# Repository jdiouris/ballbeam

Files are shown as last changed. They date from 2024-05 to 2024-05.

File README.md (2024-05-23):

# Asservissement d'une balle sur un plan incliné
Ce dépôt fournit les fichiers permettant de réaliser l'asservissement d'une balle sur un plan incliné en utilisant un corecteur PID. 
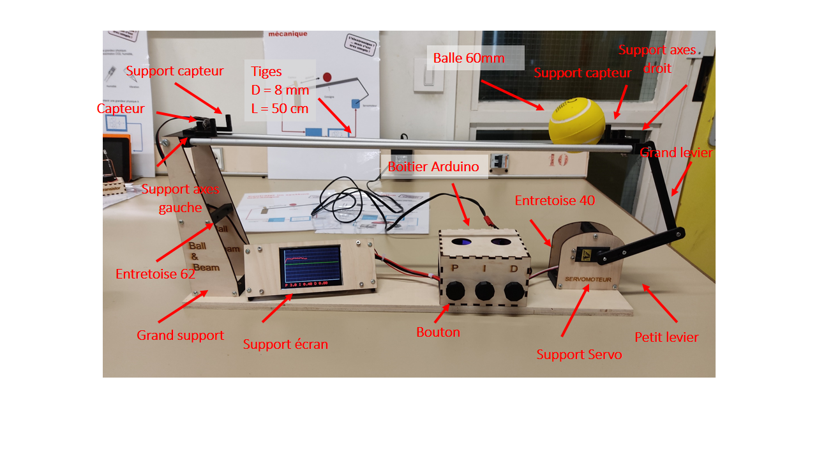
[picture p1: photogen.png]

## Principe
La balle roule sur deux axes en aluminium dont l'inclinaison est réglée par un système de leviers relié à un servomoteur standard. La position de la balle est déterminée par un capteur de distance VL53L0X, que l'on peut trouver monté sur une carte par exemple [ici](https://www.amazon.fr/gp/product/B086TSKJBT/ref=ppx_yo_dt_b_search_asin_title?ie=UTF8&psc=1). 

L'asservissement est réalisé par un Arduino Uno. L'affichage graphique est réalisé au moyen d'un arduino Mega et d'un afficheur graphique. Les deux cartes Arduino communiquent par un lien série.

## Câblage
Les différents circuits sont interconnectés selon le tableau suivant.

| PIN Arduino | Description |
| --- | ---  |
| D5 | Impulsion servo|
| A0 | Potentiomètre 0 |
| A1 | Potentiomètre 1 |
| A2 | Potentiomètre 2 |
| D3 | Alim VL53L0X |
|SCL | SCL VL53L0X |
|SDA | SDA VL53L0X |
| D1 TX| lien série, connecté au D53 de l'arduino Mega |

La figure ci-desous donne le détail du cablage.

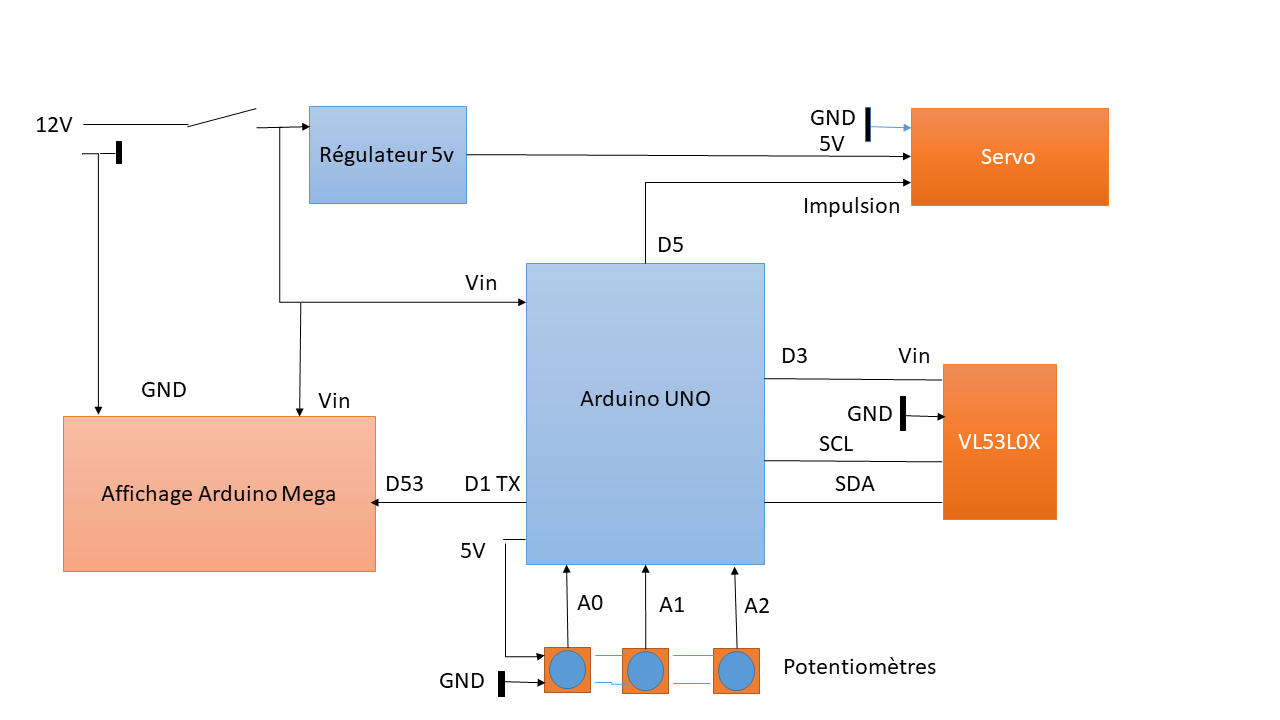
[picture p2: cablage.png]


## Mécanique

La mécanique est réalisée en découpe et gravure laser dans du contreplaqué 3mm et en impression 3D.

Les pièces dont décrites ici:

|Pièces | Fichiers source (conception) | Fichiers de fabrication | Nombre d'exemplaires |
| --- | ---  | --- |  --- |
|Boitier arduino | boitier.lbrn2| boitier.dxf | 1 |
| Support servo | supservo.lbrn2 | supservo.dxf | 1 |
| Support écran | supecran.lbrn2 | supecran.dxf | 1|
| Support  gauche | grandsupport.lbrn2 | grandsupport.dxf | 1|
| Support axes droit | supaxedroit.scad | supaxedroit.stl | 1|
| Support axe gauche | supaxegauche.scad | supaxegauche.stl | 1 |
|petit levier | levier.scad | petitlevier.stl | 1|
|grand levier | levier.scad | grandlevier.stl | 1 |
|Support carte Mega | megasupport.scad | megasupport.stl | 1 |
|Support plaque écran | msupplaqueecrant.scad | supplaqueecran.stl | 2 \
|Support capteur | supcapt.scad | supcapt.stl | 2 
| entretoise 62 |entretoises.scad | entretoise62.stl |4|
| entretoise 40 |entretoises.scad | entretoise40.stl |3|

Les fichiers dxf sont destiné à une découpe laser (contreplaqué 3mm). Les fichiers dxf à une impression 3D.

Les pièces sont indiquées sur la photo en haut de page. La photo ci-dessous donne un détail sur l'écran.

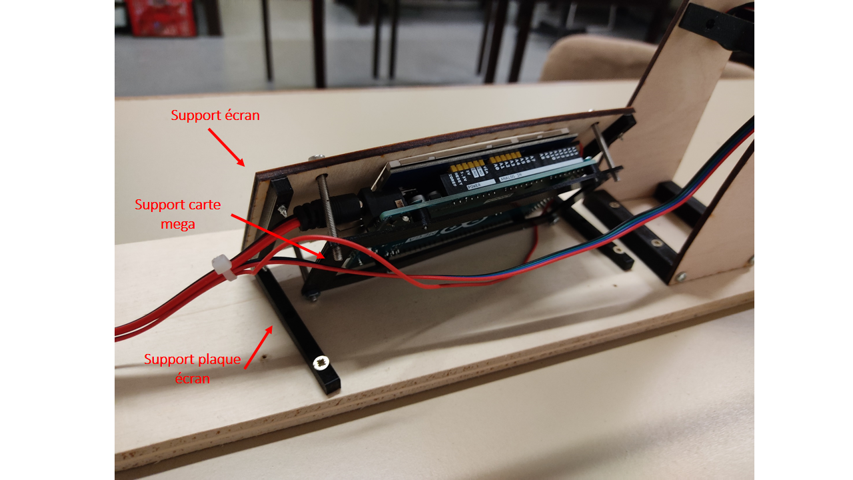
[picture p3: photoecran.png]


## Les programmes

Les deux programmes arduino sont dans les répertoires asservissement et tftgraph.

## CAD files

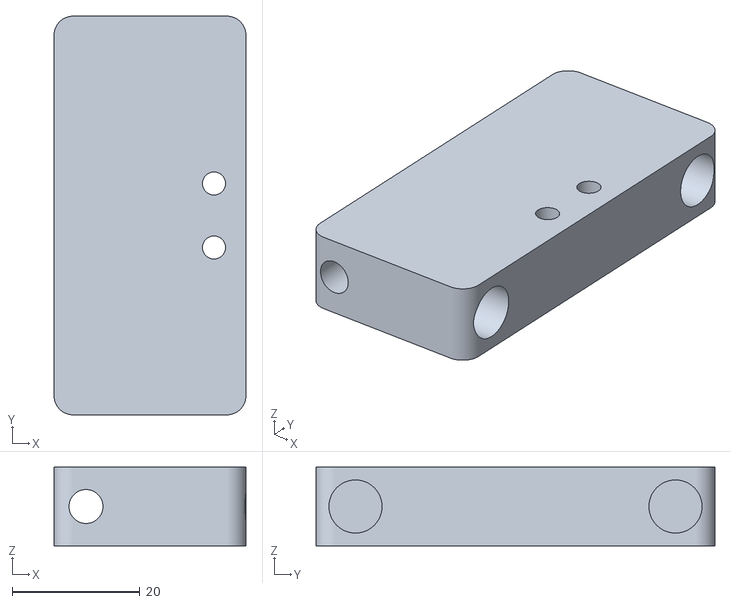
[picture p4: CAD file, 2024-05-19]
Mecanique/supaxedroit.stl
30.0 x 62.3 x 12.3

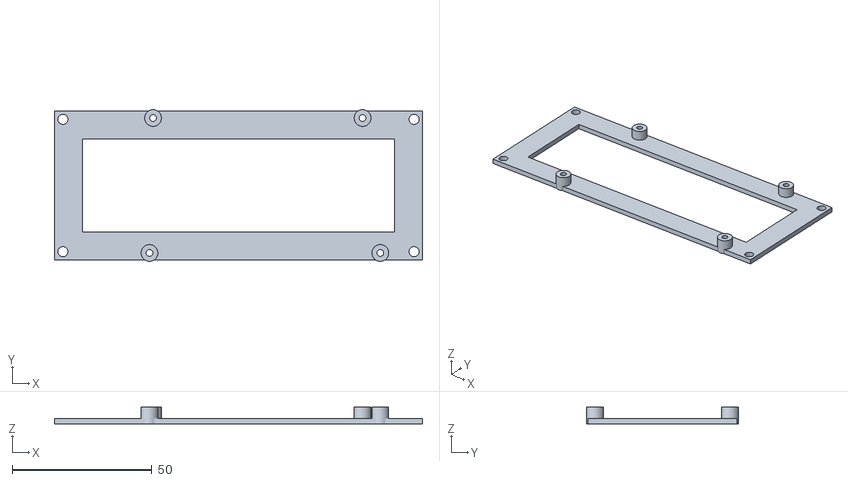
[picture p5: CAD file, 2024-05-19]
Mecanique/megasupport.stl
131.6 x 54.3 x 6.00

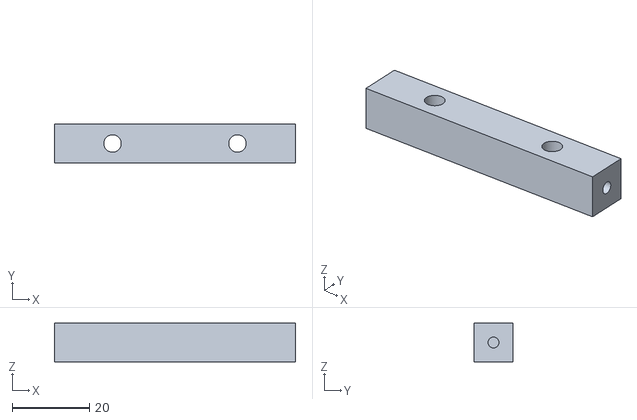
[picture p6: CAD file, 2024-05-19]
Mecanique/entretoise62.stl
62.3 x 10.0 x 10.0

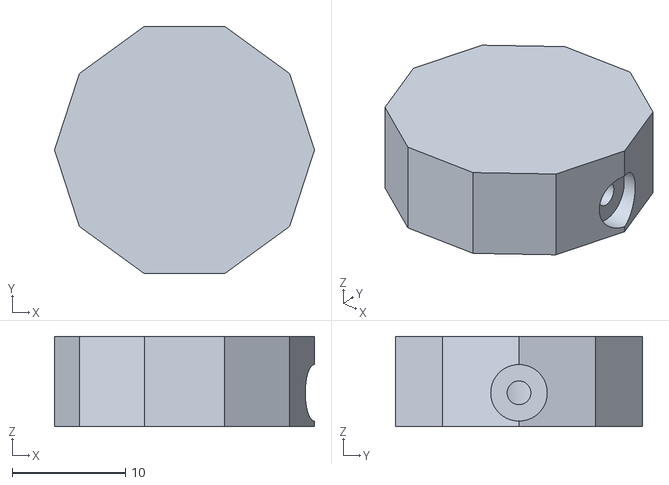
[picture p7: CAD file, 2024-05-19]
Mecanique/bouton.stl
23.0 x 21.9 x 8.00

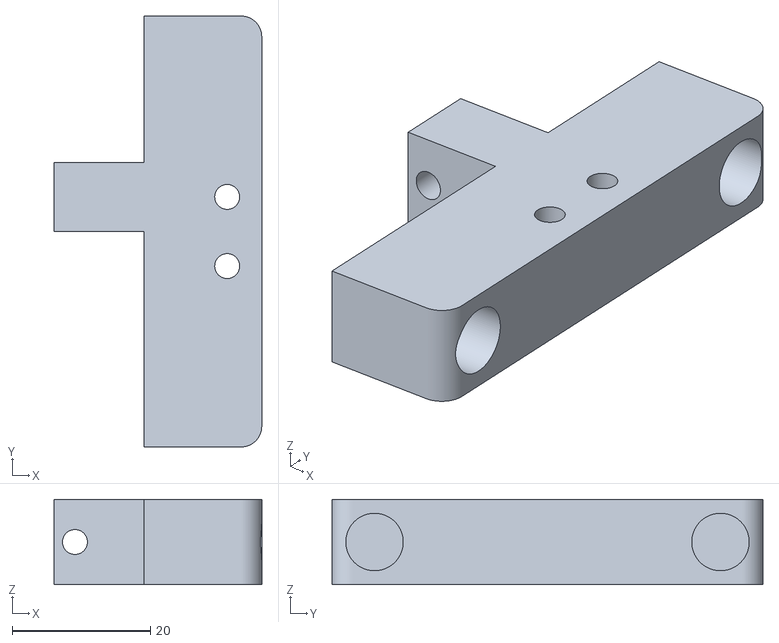
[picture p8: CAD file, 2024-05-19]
Mecanique/supaxegauche.stl
30.0 x 62.3 x 12.3

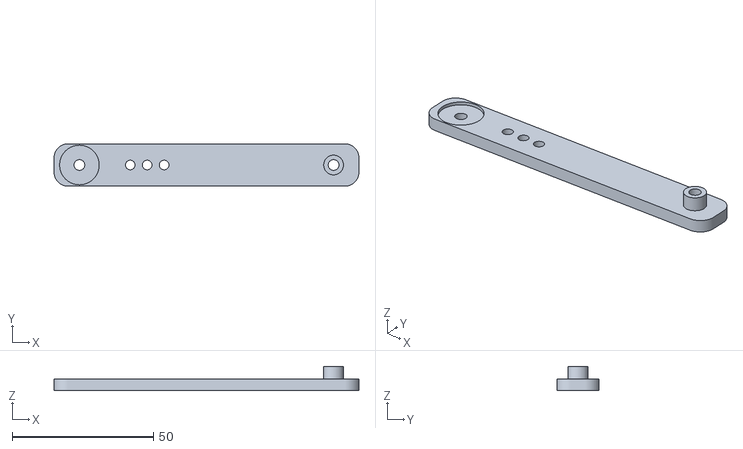
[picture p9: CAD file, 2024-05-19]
Mecanique/petitlevier.stl
108.0 x 15.0 x 8.50

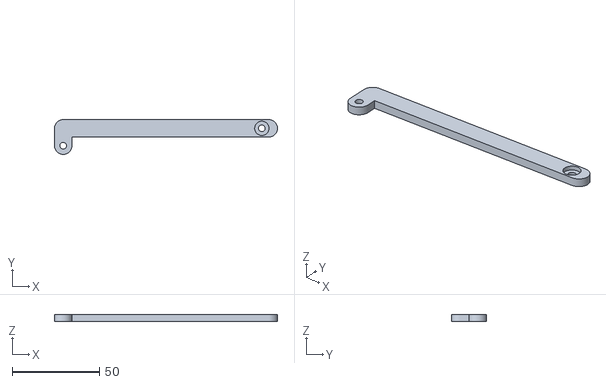
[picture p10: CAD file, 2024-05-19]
Mecanique/grandlevier.stl
128.0 x 20.0 x 4.00

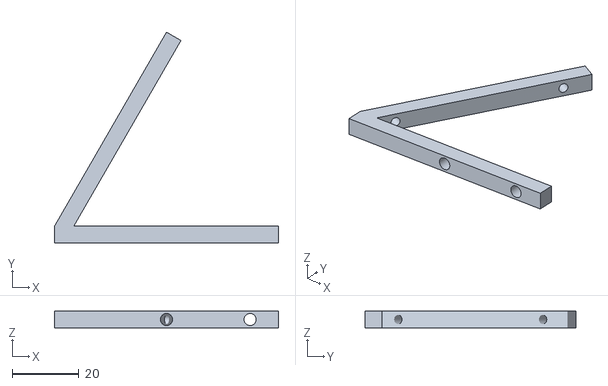
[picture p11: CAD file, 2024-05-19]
Mecanique/supplaqueecran.stl
67.0 x 63.0 x 5.00

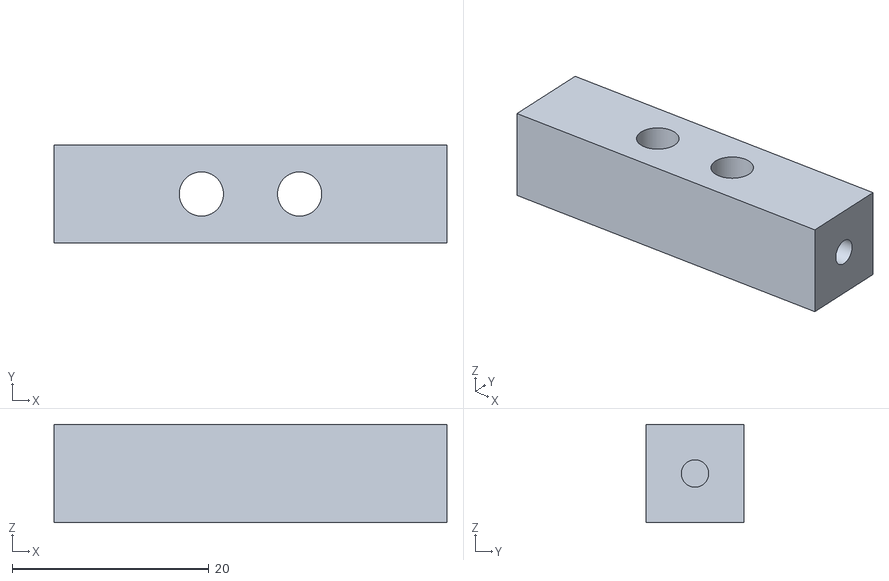
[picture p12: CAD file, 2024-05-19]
Mecanique/entretoise40.stl
40.0 x 10.0 x 10.0

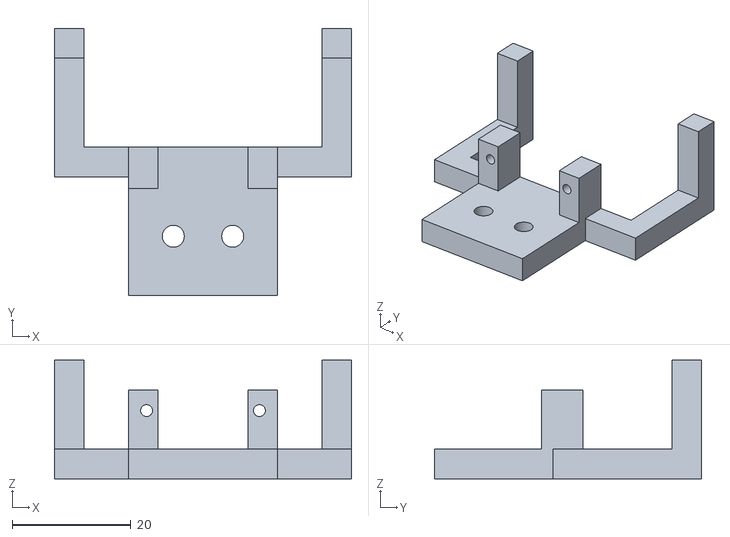
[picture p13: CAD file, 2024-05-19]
Mecanique/supcapt.stl
50.0 x 45.0 x 20.0

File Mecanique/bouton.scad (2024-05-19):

D=23;
Da=6+0.5;
H=8;
$fn=100;

difference()
{
    cylinder(d=D,h=H,$fn=10);
    cylinder(d=Da,h=H-2);
    translate([0,0,(H-2)/2]) rotate([0,90,0]) cylinder(d=2.1,h=D/2);
    translate([D/2-2,0,(H-2)/2]) rotate([0,90,0]) cylinder(d=5,h=D/2);
}

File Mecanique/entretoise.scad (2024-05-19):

//W=62.3;
W=40;
H=10;
$fn=100;

difference()
{
    cube([W,H,H]);
    translate([-1,5,5]) rotate([0,90,0]) cylinder(h=13,d=2.8);
    translate([W-12,5,5]) rotate([0,90,0]) cylinder(h=13,d=2.8);
    translate([15,5,-1]) cylinder(h=15,d=4.5);
    translate([W-15,5,-1]) cylinder(h=15,d=4.5);
}

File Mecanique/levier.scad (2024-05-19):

W=15;
W2=10;
D=14;
E=4;
L2=90+D+4;
L1=110+D+4;
$fn=100;

module rcube(x,y,z,d)
{
    union()
    {
        translate([d/2,d/2,0]) cube([x-d,y-d,z]);
        translate([d/2,0,0]) cube([x-d,d,z]);
        translate([d/2,y-d,0]) cube([x-d,d,z]);
        translate([0,d/2,0]) cube([d,y-d,z]);
         translate([x-d,d/2,0]) cube([d,y-d,z]);
        translate([d/2,d/2,0]) cylinder(h=z,d=d);
        translate([x-d/2,d/2,0]) cylinder(h=z,d=d);
         translate([d/2,y-d/2,0]) cylinder(h=z,d=d);
        translate([x-d/2,y-d/2,0]) cylinder(h=z,d=d);
    }
    
}

module petitLevier()
{
    difference()
    {
        union()
        {
        rcube(L2,W,E,10);
            translate([D/2+2+90,W/2,E]) cylinder(h=E+0.5, d=7);
        }
        translate([D/2+2,W/2,E-1]) cylinder(h=2, d=D);
        translate([D/2+2,W/2,-1]) cylinder(h=20, d=3.8);
        translate([D/2+2+18,W/2,-1]) cylinder(h=20, d=3.4);
        translate([D/2+2+24,W/2,-1]) cylinder(h=20, d=3.4);
        translate([D/2+2+30,W/2,-1]) cylinder(h=20, d=3.4);
        
        translate([D/2+2+90,W/2,-1]) cylinder(h=20, d=3.8);
        
    } 
}

module grandLevier()
{
    difference()
    {
        union()
        {
        rcube(L1,W2,E,10);
            //translate([D/2+2+110,W/2,E]) cylinder(h=E+0.5, d=12);
            rcube(10,2*W2,E,10);
        }
        //translate([D/2+2,W/2+W,E-1]) cylinder(h=2, d=D);
        translate([5,W2/2+W2,-1]) cylinder(h=20, d=3.8);
        
        
        translate([D/2+2+110,W2/2,2]) cylinder(h=20, d=8.2);
        translate([D/2+2+110,W2/2,-1]) cylinder(h=20, d=3.8);
        
    } 
}
    
//petitLevier();
mirror([0,1,0]) grandLevier();

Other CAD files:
Mecanique/boitier.dxf
Mecanique/supservo.dxf
Mecanique/grandsupport.dxf
Mecanique/supecran.dxf
Mecanique/megasupport.scad
Mecanique/supaxedroit.scad
Mecanique/supaxegauche.scad
Mecanique/supcapt.scad
Mecanique/supplaqueecran.scad

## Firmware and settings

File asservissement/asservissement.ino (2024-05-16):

#include <Servo.h>
#include "Adafruit_VL53L0X.h"
#include <MsTimer2.h>

Adafruit_VL53L0X lox = Adafruit_VL53L0X();
/* ----------------------------------------*/
/* Démo sonar                              */
/*                                         */
// Broches                                  

// servo : 5
#define SERVOPIN 5

#define IND 2
#define ALIMC 3

// potentiometres
#define P1 1
#define P0 0
#define P2 2

// valeurs extrèmes servo
#define minServo 600
#define maxServo 1500
// PID
// float kp=1;
// float kd=0.5;
// float ki=0.4;
 float kp=3;
 float kd=0.8;
 float ki=0.4;
 
 float kkd=0;
 float kki=0;
 float Te=40e-3;
 float consigne=250;
 float erreur;
 float erreurP;
 float integrale;
 float deriv;
 // Moyennage mesures
 float alpha=0.8;
 float alphad=0.85;
 
 // Flag Timer période d'échantillonnage
 int fchange;
 float dCor;
 int distance;
 float angle;
 float angleZero;
// servo rotation
 Servo servo;
 //

int fcoef=1;   // envoie des coefs

int t=0;


void testAngle()
{
  float pas=1;
  angle=minServo;
  while (1)
  {
   if (angle>(maxServo-1)) pas=-1;
   if (angle<(minServo+1)) pas=1;
   servo.writeMicroseconds(angle);
   Serial.print(angle);Serial.println();
   delay(4); 
  }
}

// Interruprtion toute les période d'échantillonage
void period()
{  
  fchange=1;
}

int mesDistance(int N)
{
  float distance=0;
  for (int  i=0; i<N; i++)
  {
     while (!lox.isRangeComplete());
          distance+=lox.readRange();
  }
  return (int)(distance/N+0.5);
  
}

void setup() {   
  /* Initialise le port série */
  Serial.begin(57600);
  while (!Serial);
  pinMode(IND,OUTPUT);
  
  digitalWrite(IND,0);
  pinMode(ALIMC,OUTPUT);
  digitalWrite(ALIMC,1);
  // Servo 

  angleZero=(minServo+maxServo)/2;
  angle=angleZero;
  

  // Init capteur de distance VL53L0X
  while (!lox.begin()) {
    Serial.println(F("Failed to boot VL53L0X"));
    digitalWrite(ALIMC,0);
    delay(100);
    digitalWrite(ALIMC,1);
    delay(100);
  }

  lox.startRangeContinuous();

  // Asservissement
  erreurP=0;
  integrale=0;
  deriv=0;
  kkd=kd/Te;
  kki=ki*Te;
  
  // Servo
  servo.writeMicroseconds(minServo);
  servo.attach(SERVOPIN);
//  for (int a=minServo; a<=angleZero; a++)
//  {
//      servo.writeMicroseconds(a);
//      delay(2);
//  }
  delay(100);
  // Interruption périodique
  MsTimer2::set(40, period); // 100ms period
  MsTimer2::start();
  
}





void loop() {

if (fchange==1)
{
    digitalWrite(IND,1);
  
    fchange=0;
  
    while (!lox.isRangeComplete());
    distance=distance*alpha+(1-alpha)*lox.readRange();
 

    // Asservissement
    erreur=distance-consigne;
    integrale+=kki*erreur;
    if (integrale>maxServo-angleZero) integrale=maxServo-angleZero;
    if (integrale<minServo-angleZero) integrale=minServo-angleZero;
    deriv=alphad*deriv+(distance-erreurP)*kkd*(1-alphad);
    angle=erreur*kp+deriv+integrale+angleZero;

    erreurP=distance;
    
    // Saturation comande
    if (angle>maxServo) angle=maxServo;
    if (angle<minServo) angle=minServo;
    // commande
    servo.writeMicroseconds(angle);
     
     Serial.print(distance); 
     if (fcoef==1)
     {
     Serial.print(","); Serial.print(int(kp*100));
     Serial.print(","); Serial.print(int(ki*100));
     Serial.print(","); Serial.print(int(kd*100));
     fcoef=0;
     }
     //Serial.print(","); Serial.print(angle);
     Serial.println();
     int v=1023-analogRead(P2);
     float x=(v/100)/2.0;
     if (x!=kp) { kp=x; fcoef=1;}
      v=1023-analogRead(P1);
      x=(v/100)/10.0;
      if (x!=ki) { ki=x; kki=ki*Te; fcoef=1; }
      v=1023-analogRead(P0);
      x=(v/100)/10.0;
      if (x!=kd) { kd=x; kkd=kd/Te; fcoef=1; }
     

     digitalWrite(IND,0);


}


}

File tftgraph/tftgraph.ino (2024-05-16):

#define LCD_CS A3 // Chip Select goes to Analog 3
#define LCD_CD A2 // Command/Data goes to Analog 2
#define LCD_WR A1 // LCD Write goes to Analog 1
#define LCD_RD A0 // LCD Read goes to Analog 0
#define LCD_RESET A4 // Can alternately just connect to Arduino's reset pin

#include <SPI.h>          // f.k. for Arduino-1.5.2
#include "Adafruit_GFX.h"// Hardware-specific library
#include <MCUFRIEND_kbv.h>
MCUFRIEND_kbv tft;

#define SERIALRX 53
#define SERIALTX 51

#include <SoftwareSerial.h>

SoftwareSerial mySerial(SERIALRX, SERIALTX); // RX, TX


// Assign human-readable names to some common 16-bit color values:
#define	BLACK   0x0000
#define	BLUE    0x001F
#define	RED     0xF800
#define	GREEN   0x07E0
#define CYAN    0x07FF
#define MAGENTA 0xF81F
#define YELLOW  0xFFE0
#define WHITE   0xFFFF
#define GRAY    0b0100001000001000

int W;  // largeur écran
int H;  // hauteur écran

int ymax=450;
#define Nmax 440
int xmax=Nmax;
int ymin=0;
int xmin=0;

int mx=30;
int my=40;
int w;
int h;

int  d[Nmax];

int xscale(float x)
{
  return (int)(w*x/xmax+mx);
}

int yscale(float y)
{
   return (int)(H-h*y/ymax-my);
}


int distance;
int x;
int xa;
int ya;
int kp;
int ki;
int kd;
int state;



void setup(void) {
    Serial.begin(115200);
    mySerial.begin(57600);
    
    
    uint16_t ID = tft.readID(); //
    //Serial.print("ID = 0x");
    //Serial.println(ID, HEX);
    if (ID == 0xD3D3) ID = 0x9481; // write-only shield

  tft.begin(ID);
  H = tft.width();
  W = tft.height();
  w=W-mx-10;   // largeur du graphe
  h=H-my-10;   // hauteur du graphe
  Serial.println(W);
  Serial.println(H);
  tft.fillScreen(BLACK);
  tft.setRotation(3);
  tft.setTextSize(3);
  tft.setCursor(30, 30);
  tft.setTextColor(WHITE);
  tft.println("Ball & Beam");
  tft.setCursor(30, 100);
  tft.setTextColor(RED);
  tft.println("(c) IETR 2023");
  delay(1000);
   tft.setTextSize(1);
   tft.fillScreen(BLACK);
   tft.drawFastHLine(mx,h+10,w,WHITE);
   tft.drawFastVLine(mx,yscale(ymax),h,WHITE);
   for (int i=10; i<=Nmax; i+=10) tft.drawFastVLine(xscale(i),10,h,GRAY);
   for (int i=50; i<=ymax; i+=50) tft.drawFastHLine(mx,yscale(i),w,GRAY);
    tft.drawFastHLine(mx,yscale(250),w,GREEN);



      
       //tft.fillRect(0, 48 + 63, wid, 100, BLUE);

       distance=0;
       x=0;
       xa=-1;
       kp=ki=kd=state=0;
       for (int i=0; i<Nmax; i++) d[i]=0;
       tft.setTextSize(3);
}

void grosPixel(int x,int y, int color)
{
  tft.drawPixel(x,y,color);
  tft.drawPixel(x-1,y,color);
  tft.drawPixel(x-1,y-1,color);
  tft.drawPixel(x+1,y,color);
  tft.drawPixel(x+1,y+1,color);
}
char s[40];
void printCoef()
{
  tft.fillRect(mx,h+11,w,40,BLACK);
  int d1kp=kp/100;
  int d2kp=(kp-d1kp*100);
  int d1kd=kd/100;
  int d2kd=(kd-d1kd*100);
  int d1ki=ki/100;
  int d2ki=(ki-d1ki*100);
  sprintf(s,"P %d.%d I %d.%d D %d.%d",d1kp,d2kp,d1ki,d2ki,d1kd,d2kd);
  tft.setCursor(mx,h+25);
  tft.print(s);
}

void loop(void) {
  if (mySerial.available())
  {
    char c=mySerial.read();
    if ((c>='0')&&(c<='9'))
    { 
      switch (state)
      {
        case 0: distance=distance*10+(c-'0'); break;
        case 1: kp=kp*10+(c-'0'); break;
        case 2: ki=ki*10+(c-'0'); break;
        case 3: kd=kd*10+(c-'0'); break;
      }
    }
    if (c==',') state++;
    if (c==10) {
      Serial.println(distance);
      Serial.println(kp);
      Serial.println(ki);
      Serial.println(kd);
      x++; 
      if (x>=xmax)
      {
        x=0;
       for (int i=0; i<Nmax; i++) grosPixel(xscale(i),d[i],BLACK);
       // tft.fillScreen(BLACK);
        tft.drawFastHLine(mx,h+10,w,WHITE);
        tft.drawFastVLine(mx,10,h,WHITE);
        for (int i=10; i<Nmax; i+=10) tft.drawFastVLine(xscale(i),10,h,GRAY);
        for (int i=50; i<ymax; i+=50) tft.drawFastHLine(mx,yscale(i),w,GRAY);
        tft.drawFastHLine(mx,yscale(250),w,GREEN);
      }
      int xx=xscale(x);
     
      if (distance>ymax) distance=ymax;
      if (distance<ymin) distance=ymin;
      int yy=yscale(distance);
      grosPixel(xx,yy,RED);
      d[x]=yy;
      //
      if (kp!=0)printCoef();
      distance=kp=ki=kd=state=0;
    }
    
  }
    
    
}
